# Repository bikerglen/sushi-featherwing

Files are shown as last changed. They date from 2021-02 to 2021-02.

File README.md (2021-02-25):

# sushi-featherwing

The Sushi FeatherWing is for use with the Adafruit HUZZAH ESP32 Feather and the slim 640x48 LCDs found in the various dragon, wizard, and fairy magic wand toys.

Boards available at OSH Park: https://oshpark.com/shared_projects/a6137iE9

The required 22-pin, 0.5mm pitch FFC connector is Amphenol part # SFV22R-2STE1HLF, Digi-Key part # 609-4319-1-ND.

I picked Vled and R1 to limit the backlight current to 5mA on my module.

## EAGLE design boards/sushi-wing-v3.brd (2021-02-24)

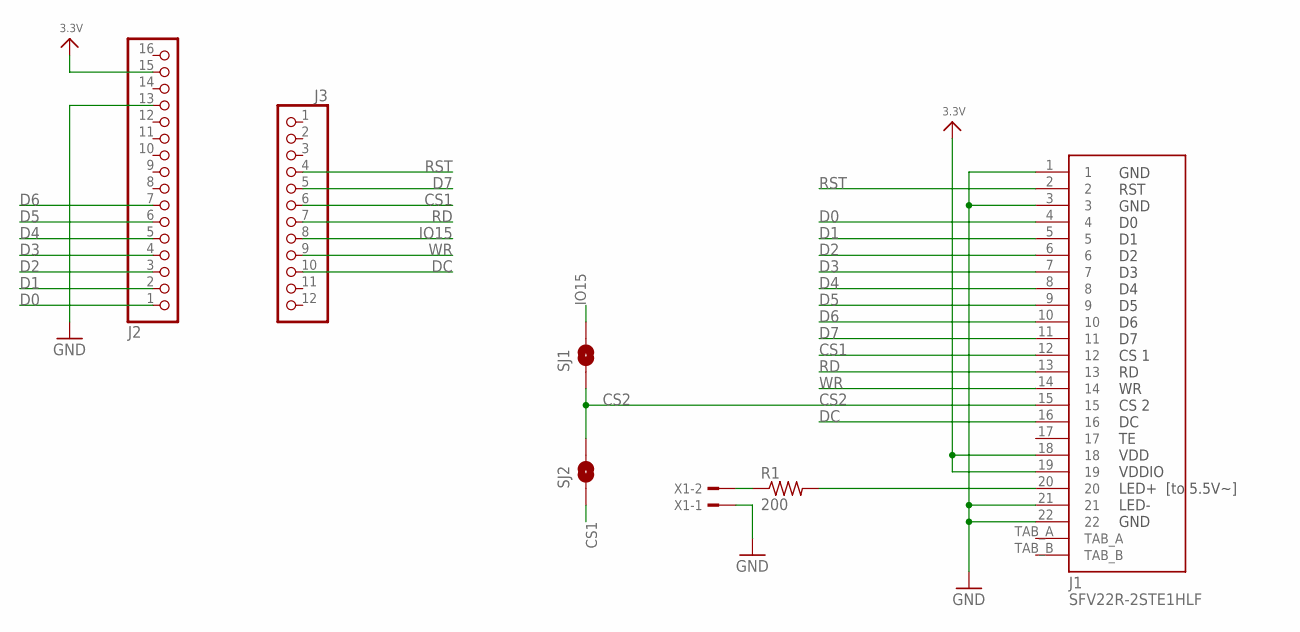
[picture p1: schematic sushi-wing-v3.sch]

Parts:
J1: SFV22R-2STE1HLF
J2: HEADER-1X16_MIN; 1X16_ROUND_MIN
J3: HEADER-1X12_MIN; 1X12_ROUND_MIN
R1: 200; R1206
SJ1, SJ2: SOLDERJUMPERNO; SJ_2S-NO
X1: TSW-102-02-S-S-RA

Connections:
3.3V: J1.18, J1.19, J2.15
CS1: J1.12, J3.6, SJ2.1
CS2: J1.15, SJ1.1, SJ2.2
D0: J1.4, J2.1
D1: J1.5, J2.2
D2: J1.6, J2.3
D3: J1.7, J2.4
D4: J1.8, J2.5
D5: J1.9, J2.6
D6: J1.10, J2.7
D7: J1.11, J3.5
DC: J1.16, J3.10
GND: J1.1, J1.3, J1.21, J1.22, J2.13, X1.1
IO15: J3.8, SJ1.2
unnamed: R1.1, X1.2
unnamed: J1.20, R1.2
RD: J1.13, J3.7
RST: J1.2, J3.4
WR: J1.14, J3.9

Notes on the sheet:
GND RST GND D0 D1 D2 D3 D4 D5 D6 D7 CS 1 RD WR CS 2 DC TE VDD VDDIO LED+ [to 5.5V~] LED- GND

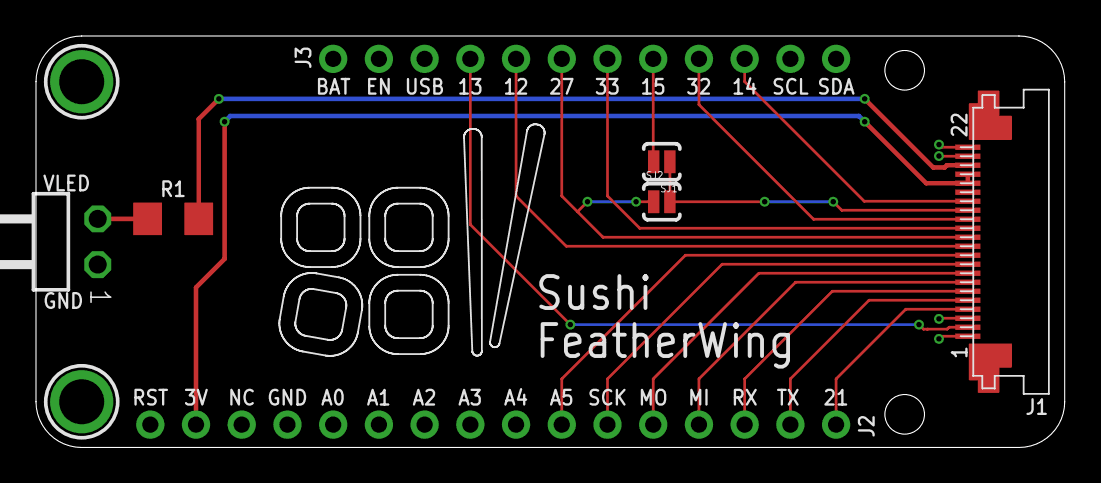
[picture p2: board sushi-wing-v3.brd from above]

Board: 2 copper layers, 57.1 x 22.9 mm, 9 parts (0 on the bottom side), 19 nets.

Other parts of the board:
U$31, U$32: MOUNTINGHOLE2.5; MOUNTINGHOLE_2.5_PLATED

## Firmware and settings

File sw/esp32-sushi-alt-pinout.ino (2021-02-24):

//
// ###########################################################
//
//      ãƒžã‚¸ãƒ§ã‚«ã‚¢ã‚¤ãƒªã‚¹ 640*48px ç´°é•·LCD å‹•ä½œãƒ†ã‚¹ãƒˆã‚³ãƒ¼ãƒ‰
//
//      Hideto Kikuchi / PJ (@pcjpnet) - http://pc-jp.net/
//
// ###########################################################
//
//
//      Example Code for ESP32 Dev Module
//      Require LovyanGFX 0.3.6 Library
//
//      Pinout modified for Adafruit ESP32 Feather 
//      Huzzah + Sushi FeatherWing
//        -- @bikerglen
//
//
// ####################  LCD Pin Assignments  ####################
//  
//  0.5mm Pitch - 22Pin
//  
//  1   - GND   [to GND]
//  2   - RST   [to ESP32 - 32]
//  3   - GND   [to GND]
//  4   - D0    [to ESP32 - 12]
//  5   - D1    [to ESP32 - 13]
//  6   - D2    [to ESP32 - 26]   *** 5 
//  7   - D3    [to ESP32 - 25]   *** 18
//  8   - D4    [to ESP32 - 17]
//  9   - D5    [to ESP32 - 16]
//  10  - D6    [to ESP32 - 27]
//  11  - D7    [to ESP32 - 14]
//  12  - CS 1  [to ESP32 - 33]
//  13  - RD    [to ESP32 - 2]    *** 21
//  14  - WR    [to ESP32 - 4]
//  15  - CS 2  [to ESP32 - 33]   *** 19
//  16  - DC    [to ESP32 - 15]
//  17  - TE    [OPEN]
//  18  - VDD   [to 3.3V]
//  19  - VDDIO [to 3.3V]
//  20  - LED+  [to 5.5V~]
//  21  - LED-  [to GND]
//  22  - GND   [to GND]
//
// â€» PSRAMã‚’ä½¿ç”¨ã™ã‚‹å ´åˆã¯ GPIO 16 , 17 ã¯ä½¿ç”¨ã§ããªã„ã®ã§æ³¨æ„ã€‚

#include <LovyanGFX.hpp>


struct LGFX_Config {
  static constexpr int gpio_wr  = 32; //to LCD WR(14)
  static constexpr int gpio_rd  = 33; //to LCD RD(13)
  static constexpr int gpio_rs  = 14; //to LCD DC(16)
  static constexpr int gpio_d0  = 21; //to LCD D0(4)
  static constexpr int gpio_d1  = 17; //to LCD D1(5)
  static constexpr int gpio_d2  = 16; //to LCD D2(6)
  static constexpr int gpio_d3  = 19; //to LCD D3(7)
  static constexpr int gpio_d4  = 18; //to LCD D4(8)
  static constexpr int gpio_d5  =  5; //to LCD D5(9)
  static constexpr int gpio_d6  =  4; //to LCD D6(10)
  static constexpr int gpio_d7  = 12; //to LCD D7(11)
  // gpio_cs(12/15) = 27
  // gpio_rst(2)    = 13
};


static lgfx::LGFX_PARALLEL<LGFX_Config> lcd;

static lgfx::Panel_ILI9342 panel;

static lgfx::LGFX_Sprite buf; // [640 * 48] Buffer

// ===== THIS IS SUSHI ===== //
extern const uint16_t sushi[];
uint16_t i = 0;


// ===== ENTER SUSHI SHOP ===== //
void setup() {
// è¨­å®šã§ãã‚‹ã‚¯ãƒ­ãƒƒã‚¯ã¯20MHzï½ž6.7MHzã§ã™ã€‚ã¾ãŸã€80MHzã‚’æ•´æ•°ã§å‰²ã£ãŸå€¤ã«èª¿æ•´ã•ã‚Œã¾ã™ã€‚
// 20MHz, 16MHz, 13.4MHz, 11.5MHz, 10MHz, 88.9MHz, 8MHz, 7.3MHz, 6.7MHz
  panel.freq_write = 16000000;
  panel.len_dummy_read_pixel = 8;

  panel.spi_cs = 27;  //to LCD CS(15)
  panel.spi_dc = -1;
  panel.gpio_rst = 13;  //to LCD RST(2)

  panel.gpio_bl  = -1;
  panel.pwm_ch_bl = -1;
  panel.backlight_level = true;

  panel.memory_width  = 320;
  panel.memory_height = 240;

  panel.panel_width  = 320;
  panel.panel_height = 96;

  panel.offset_x = 0;
  panel.offset_y = 144;

  panel.rotation = 0;

  panel.offset_rotation = 0;

  lcd.setPanel(&panel);

  lcd.init();
  lcd.setColorDepth(16);

  lcd.setRotation(0); // 0 or 2

  buf.setColorDepth(16);
  buf.createSprite(640, 48);
  buf.setSwapBytes(true);
}


// ===== MAIN SUSHI LOOP ===== //
void loop() {
  for (int j = 0; j < 7; j++)
  {
    buf.pushImage(i - 50 + j * 100, 0, 48, 48, sushi);

// rolling sushi.
//  buf.pushImageRotateZoom(i - 25 + j * 100, 24, 24, 24, i + j * 100, 1.0f, 1.0f, 48, 48, sushi);

// zooming sushi.
//  buf.pushImageRotateZoom(i - 20 + j * 100, 24, 24, 24, 0, 0.5f + ((float)i/100 + j)/5, 0.5f + ((float)i/100 + j)/5, 48, 48, sushi);
  }

  lcd_buffer_write();
  i++;
  if (i == 100) {
    i = 0;
  }
  delay(5);
}


// ===== 640*48px Buffer to 320*96px LCD ===== //
inline void lcd_buffer_write() {
  lcd.setAddrWindow(0, 0, 320, 96);
  lcd.pushPixels((lgfx::swap565_t*)buf.getBuffer(), 640 * 48);
}



// ===== THIS IS 48*48px SUSHI ARRAY ===== //
constexpr uint16_t sushi[2304] = {
    0x0000, 0x0000, 0x0000, 0x0000, 0x0000, 0x0000, 0x0000, 0x0000, 0x0000, 0x0000, 0x0000, 0x0000, 0x0000, 0x0000, 0x0000, 0x0000,
    0x0000, 0x0000, 0x0000, 0x0000, 0x0000, 0x0000, 0x0000, 0x0000, 0x0000, 0x0000, 0x0000, 0x0000, 0x0000, 0x0000, 0x0000, 0x0000,
    0x0000, 0x0000, 0x0000, 0x0000, 0x0000, 0x0000, 0x0000, 0x0000, 0x0000, 0x0000, 0x0000, 0x0000, 0x0000, 0x0000, 0x0000, 0x0000,
    0x0000, 0x0000, 0x0000, 0x0000, 0x0000, 0x0000, 0x0000, 0x0000, 0x0000, 0x0000, 0x0000, 0x0000, 0x0000, 0x0000, 0x0000, 0x0000,
    0x0000, 0x0000, 0x0000, 0x0000, 0x0000, 0x0000, 0x0000, 0x0000, 0x0000, 0x0000, 0x0000, 0x0000, 0x0000, 0x0000, 0x0000, 0x0000,
    0x0000, 0x0000, 0x0000, 0x0000, 0x0000, 0x0000, 0x0000, 0x0000, 0x0000, 0x0000, 0x0000, 0x0000, 0x0000, 0x0000, 0x0000, 0x0000,
    0x0000, 0x0000, 0x0000, 0x0000, 0x0000, 0x0000, 0x0000, 0x0000, 0x0000, 0x0000, 0x0000, 0x0000, 0x0000, 0x0000, 0x0000, 0x0000,
    0x0000, 0x0000, 0x0000, 0x0000, 0x0000, 0x0000, 0x0000, 0x0000, 0x0000, 0x0000, 0x0000, 0x0000, 0x0000, 0x0000, 0x0000, 0x0000,
    0x0000, 0x0000, 0x0000, 0x0000, 0x0000, 0x0000, 0x0000, 0x0000, 0x0000, 0x0000, 0x0000, 0x0000, 0x0000, 0x0000, 0x0000, 0x0000,
    0x0000, 0x0000, 0x0000, 0x0000, 0x0000, 0x0000, 0x0000, 0x0000, 0x0000, 0x0000, 0x0000, 0x0000, 0x0000, 0x0000, 0x0000, 0x0000,
    0x0000, 0x0000, 0x0000, 0x0000, 0x0000, 0x0000, 0x0000, 0x0000, 0x0000, 0x0000, 0x0000, 0x0000, 0x0000, 0x0000, 0x0000, 0x0000,
    0x0000, 0x0000, 0x0000, 0x0000, 0x0000, 0x0000, 0x0000, 0x0000, 0x0000, 0x0000, 0x0000, 0x0000, 0x0000, 0x0000, 0x0000, 0x0000,
    0x0000, 0x0000, 0x0000, 0x0000, 0x0000, 0x0000, 0x0000, 0x0000, 0x0000, 0x0000, 0x0000, 0x0000, 0x0000, 0x0000, 0x0000, 0x0000,
    0x0000, 0x0000, 0x0000, 0x0000, 0x0000, 0x0000, 0x0000, 0x0000, 0x0000, 0x0000, 0x0000, 0x0000, 0x0000, 0x0000, 0x0000, 0x0000,
    0x0000, 0x0000, 0x0000, 0x0000, 0x0000, 0x0000, 0x0000, 0x0000, 0x0000, 0x0000, 0x0000, 0x0000, 0x0000, 0x0000, 0x0000, 0x0000,
    0x0000, 0x0000, 0x0000, 0x0000, 0x0000, 0x0000, 0x0000, 0x0000, 0x0000, 0x0000, 0x0000, 0x0000, 0x0000, 0x0000, 0x0000, 0x0000,
    0x0000, 0x0000, 0x0000, 0x0000, 0x0000, 0x0000, 0x0000, 0x0000, 0x0000, 0x0000, 0x0000, 0x0000, 0x0000, 0x0000, 0x0000, 0x0000,
    0x0000, 0x0000, 0x0000, 0x0000, 0x0000, 0x0000, 0x0000, 0x0000, 0x0000, 0x0000, 0x0000, 0x0000, 0x0000, 0x0000, 0x0000, 0x0000,
    0x0000, 0x0000, 0x0000, 0x0000, 0x0000, 0x0000, 0x0000, 0x0000, 0x0000, 0x0000, 0x0000, 0x0000, 0x0000, 0x0000, 0x0000, 0x0000,
    0x0000, 0x0000, 0x0000, 0x0000, 0x0000, 0x0000, 0x0000, 0x0000, 0x0000, 0x0000, 0x0000, 0x0000, 0x0000, 0x0000, 0x0000, 0x0000,
    0x0000, 0x0000, 0x0000, 0x0000, 0x0000, 0x0000, 0x0000, 0x0000, 0x0000, 0x0000, 0x0000, 0x0000, 0x0000, 0x0000, 0x0000, 0x0000,
    0x0000, 0x0000, 0x0000, 0x0000, 0x0000, 0x0000, 0x0000, 0x0000, 0x0000, 0x0000, 0x0000, 0x0000, 0x0000, 0x0000, 0x0000, 0x0000,
    0x0000, 0x0000, 0x0000, 0x0000, 0x0000, 0x0000, 0x0000, 0x0000, 0x0000, 0x0000, 0x0000, 0x0000, 0x0000, 0x0000, 0x0000, 0x0000,
    0x0000, 0x0000, 0x0000, 0x0000, 0x0000, 0x0000, 0x0000, 0x0000, 0x0000, 0x0000, 0x0000, 0x0000, 0x0000, 0x0000, 0x0000, 0x0000,
    0x0000, 0x0000, 0x0000, 0x0000, 0x0000, 0x0000, 0x0000, 0x0000, 0x0000, 0x0000, 0x0000, 0x0000, 0x0000, 0x0000, 0x0000, 0x0000,
    0x0000, 0x0000, 0x1860, 0x69C5, 0x7A46, 0x82C8, 0x7B2B, 0x838C, 0x7BAE, 0x83AE, 0x7B2C, 0x5A07, 0x0821, 0x0000, 0x0000, 0x0000,
    0x0000, 0x0000, 0x0000, 0x0000, 0x0000, 0x0000, 0x0000, 0x0000, 0x0000, 0x0000, 0x0000, 0x0000, 0x0000, 0x0000, 0x0000, 0x0000,
    0x0000, 0x0000, 0x0000, 0x0000, 0x0000, 0x0000, 0x0000, 0x0000, 0x0000, 0x0000, 0x0000, 0x0000, 0x0000, 0x0000, 0x5143, 0xAB88,
    0xFD2E, 0xFDD0, 0xFDF0, 0xFDF1, 0xFE32, 0xFEB5, 0xFF16, 0xFEF7, 0xFEF6, 0xFEF6, 0xFED5, 0xFED5, 0xFF17, 0xFED6, 0xE551, 0x934A,
    0x5165, 0x0000, 0x0000, 0x0000, 0x0000, 0x0000, 0x0000, 0x0000, 0x0000, 0x0000, 0x0000, 0x0000, 0x0000, 0x0000, 0x0000, 0x0000,
    0x0000, 0x0000, 0x0000, 0x0000, 0x0000, 0x0000, 0x0000, 0x0000, 0x0000, 0x0000, 0x0000, 0x0000, 0x7A65, 0xFDB0, 0xFE52, 0xFDD2,
    0xFD92, 0xFD71, 0xFD30, 0xF590, 0xFDB1, 0xFD4E, 0xF52D, 0xFD6D, 0xFD8E, 0xF5AE, 0xFDCF, 0xF5F0, 0xF5F0, 0xF5D1, 0xFDF1, 0xFDF1,
    0xFE12, 0xFE32, 0xCC2C, 0x5143, 0x0000, 0x0000, 0x0000, 0x0000, 0x0000, 0x0000, 0x0000, 0x0000, 0x0000, 0x0000, 0x0000, 0x0000,
    0x0000, 0x0000, 0x0000, 0x0000, 0x0000, 0x0000, 0x0000, 0x0000, 0x0000, 0x0000, 0x0000, 0xFD6F, 0xFE74, 0xFD91, 0xFC8D, 0xFC2B,
    0xFC4A, 0xF429, 0xFD0C, 0xF4CA, 0xFC88, 0xF4A9, 0xFCC9, 0xF4E9, 0xFD08, 0xFD09, 0xF509, 0xFD09, 0xF509, 0xFD2B, 0xF5AE, 0xF5AE,
    0xF5B0, 0xF5D1, 0xFDF2, 0xFE12, 0xFCEE, 0x5143, 0x0000, 0x0000, 0x0000, 0x0000, 0x0000, 0x0000, 0x0000, 0x0000, 0x0000, 0x0000,
    0x0000, 0x0000, 0x0000, 0x0000, 0x0000, 0x0000, 0x0000, 0x0000, 0x0000, 0x1840, 0xFEB3, 0xFE54, 0xFC8D, 0xFC4A, 0xFC89, 0xFC88,
    0xFC86, 0xFDAD, 0xF528, 0xFD07, 0xFD27, 0xFD27, 0xFD47, 0xFD27, 0xF507, 0xFD07, 0xFCC6, 0xF54B, 0xFDAC, 0xF52A, 0xF4A7, 0xFCA8,
    0xF4A8, 0xF4AA, 0xF50C, 0xF54E, 0xFDB1, 0xFDB0, 0xE40A, 0x0000, 0x0000, 0x0000, 0x0000, 0x0000, 0x0000, 0x0000, 0x0000, 0x0000,
    0x0000, 0x0000, 0x0000, 0x0000, 0x0000, 0x0000, 0x0000, 0x0000, 0x0000, 0xFE72, 0xFDF3, 0xFCA9, 0xFD08, 0xFD48, 0xFD66, 0xFE2B,
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
};

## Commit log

2021-02-24 initial checkin
    [sushi-wing-v3.brd, sushi-wing-v3.sch]
2021-02-24 added gerbers
    [sushi-wing-v3.drills.xln]
2021-02-24 add link to board at osh park
2021-02-25 add FFC connector part number
2021-02-25 added note about backlight current

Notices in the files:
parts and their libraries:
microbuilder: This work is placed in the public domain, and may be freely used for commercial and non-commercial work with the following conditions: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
